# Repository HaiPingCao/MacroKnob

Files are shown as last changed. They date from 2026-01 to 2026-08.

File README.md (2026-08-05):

# ControlDeck

ControlDeck is a simple, multi-purpose, programmable volume knob built with an Arduino Pro Micro.  
It is designed as a compact hardware control interface for volume adjustment, mode switching, and custom hotkeys.

! Please ignore the grammar error, my English is bad 😭
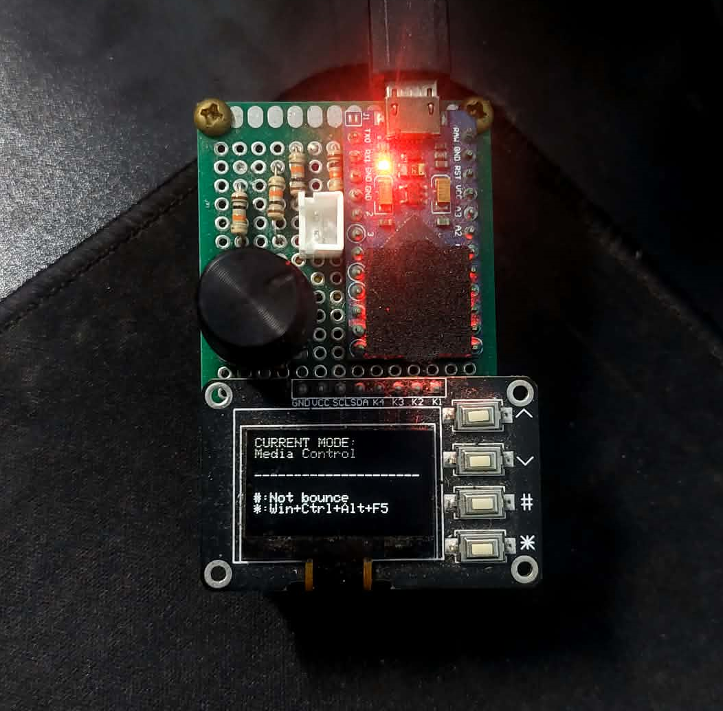
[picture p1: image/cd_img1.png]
This is my build


## Hardware

The project uses the following components:

- Arduino Pro Micro
- Rotary encoder with integrated push button
- 4 momentary push buttons
- SSD1306 OLED display (128×64)

### Circuit Setup and Wiring

| Component | Pin | Description |
| --- | --- | --- |
| Encoder CLK | 5 | Clock signal for rotation detection |
| Encoder DT  | 4 | Data signal for rotation direction detection |
| Encoder SW  | 6 | Encoder push button |
| UP Button | 10  | Switch to previous mode |
| DOWN Button | 16  | Switch to next mode |
| # Button | 14  | Special function button |
| \* Button | 15  | Triggers Win + Ctrl + Alt + F5 hotkey |

## Software

### Required Libraries

When using the Arduino IDE, install the following libraries via the Arduino Library Manager:

- **HID-Project** by NicoHood
- **Adafruit GFX Library** by Adafruit
- **Adafruit SSD1306** by Adafruit

### Driver Development

A new custom driver written in Rust is currently in early development to support more advanced features.  
See the `mk-driver` directory for details.

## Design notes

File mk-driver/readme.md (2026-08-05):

# MK Driver (a.k.a macro knob driver)

## ⚠ I postponed the development of this driver due to a lack of time, and I am already satisfied with the current build.

A volume monitor that sends real-time audio volume data to Arduino via serial port.

## Features

- Monitors system volume in real-time
- Sends volume data to Arduino via serial connection
- Auto-detects Arduino port

## Requirements

- Rust (latest stable version)
- Arduino connected via USB and open serial port

## Usage

1. Connect your Arduino via USB
2. Upload the Arduino sketch to your board
3. Run the program:

```bash
cargo run
```

The program will:

- Auto-detect the Arduino port
- Connect at 9600 baud rate
- Send volume updates when changes are detected

## Data Format

The program sends 2 bytes per update:

- Byte 1: Volume level (0-100)
- Byte 2: Mute status (0 = unmuted, 1 = muted)

## Supported Platforms

- Windows
- Linux

## Troubleshooting

**Arduino not found**

- Ensure Arduino is connected via USB
- Check if Arduino drivers are installed

**Timeout errors**

- Volume changes are only sent when detected to prevent serial overload
- Check Arduino serial buffer if issues persist
- Only one program can access the serial port at a time
- Try close Arduino IDE Serial Monitor or any other program using the serial port

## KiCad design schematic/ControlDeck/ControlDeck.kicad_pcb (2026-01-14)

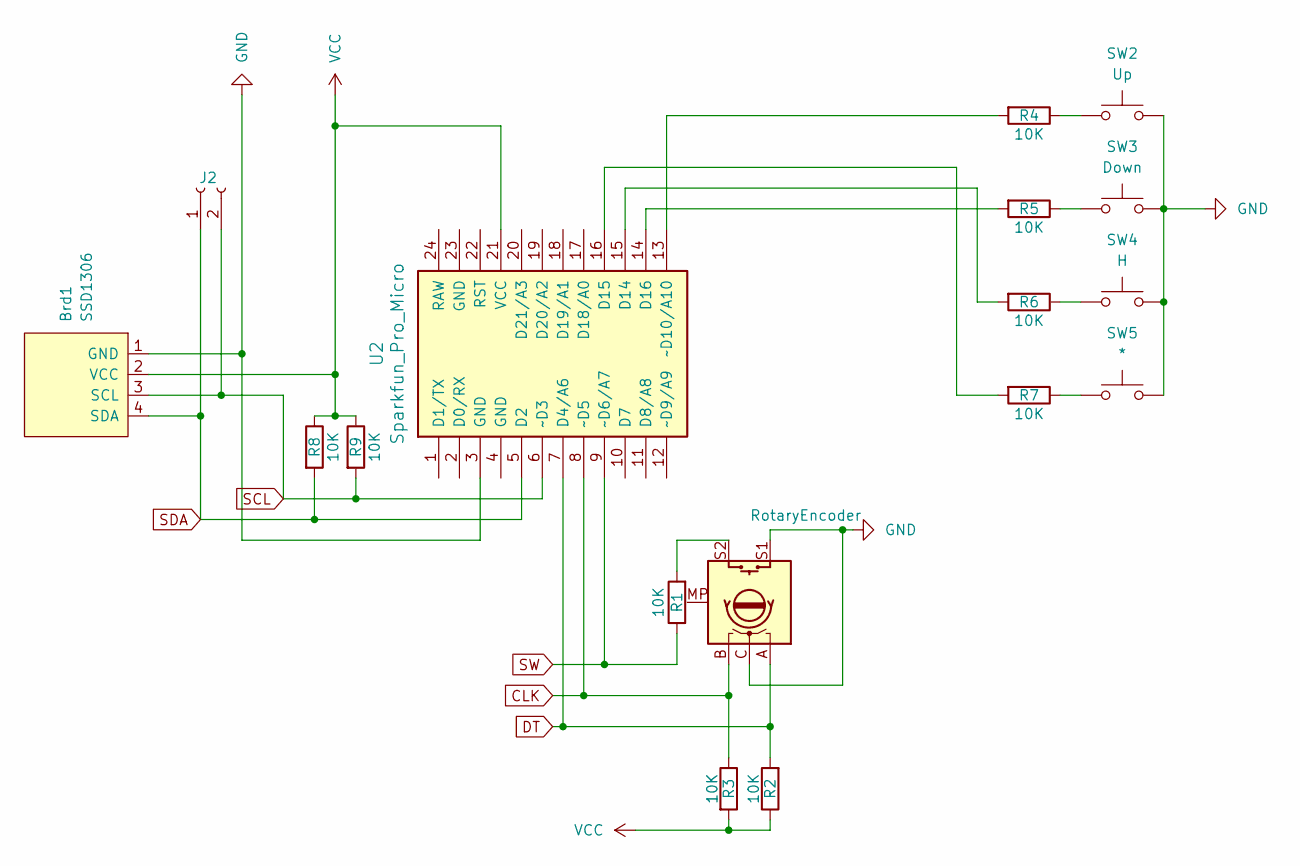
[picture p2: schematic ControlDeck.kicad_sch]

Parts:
Brd1: SSD1306; 128x64OLED
J2: Conn_01x02_Socket; JST_PH_B2B-PH-K_1x02_P2.00mm_Vertical
R1, R2, R3, R4, R5, R6, R7, R8, R9: 10K; R_Axial_DIN0204_L3.6mm_D1.6mm_P5.08mm_Horizontal
SW1: RotaryEncoder; RotaryEncoder_Alps_EC11E-Switch_Vertical_H20mm
SW2: Up; SW_SPST_CK_RS282G05A3
SW3: Down; SW_SPST_CK_RS282G05A3
SW4: H; SW_SPST_CK_RS282G05A3
SW5: *; SW_SPST_CK_RS282G05A3
U2: Sparkfun_Pro_Micro

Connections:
CLK: R3.1, SW1.B, U2.8 (~D5)
DT: R2.2, SW1.A, U2.7 (D4/A6)
GND: Brd1.1 (GND), SW1.C, SW1.S1, SW2.2, SW3.2, SW4.2, SW5.2, U2.3 (GND), U2.23 (GND)
unnamed: R1.2, SW1.S2
unnamed: R4.1, SW2.1
unnamed: R5.1, SW3.1
unnamed: R6.1, SW4.1
unnamed: R7.1, SW5.1
unnamed: R6.2, U2.15 (D14)
unnamed: R7.2, U2.16 (D15)
unnamed: R5.2, U2.14 (D16)
unnamed: R4.2, U2.13 (~D10/A10)
SCL: Brd1.3 (SCL), J2.2, R9.2, U2.6 (~D3)
SDA: Brd1.4 (SDA), J2.1, R8.2, U2.5 (D2)
SW: R1.1, U2.9 (~D6/A7)
VCC: Brd1.2 (VCC), R2.1, R3.2, R8.1, R9.1, U2.21 (VCC)

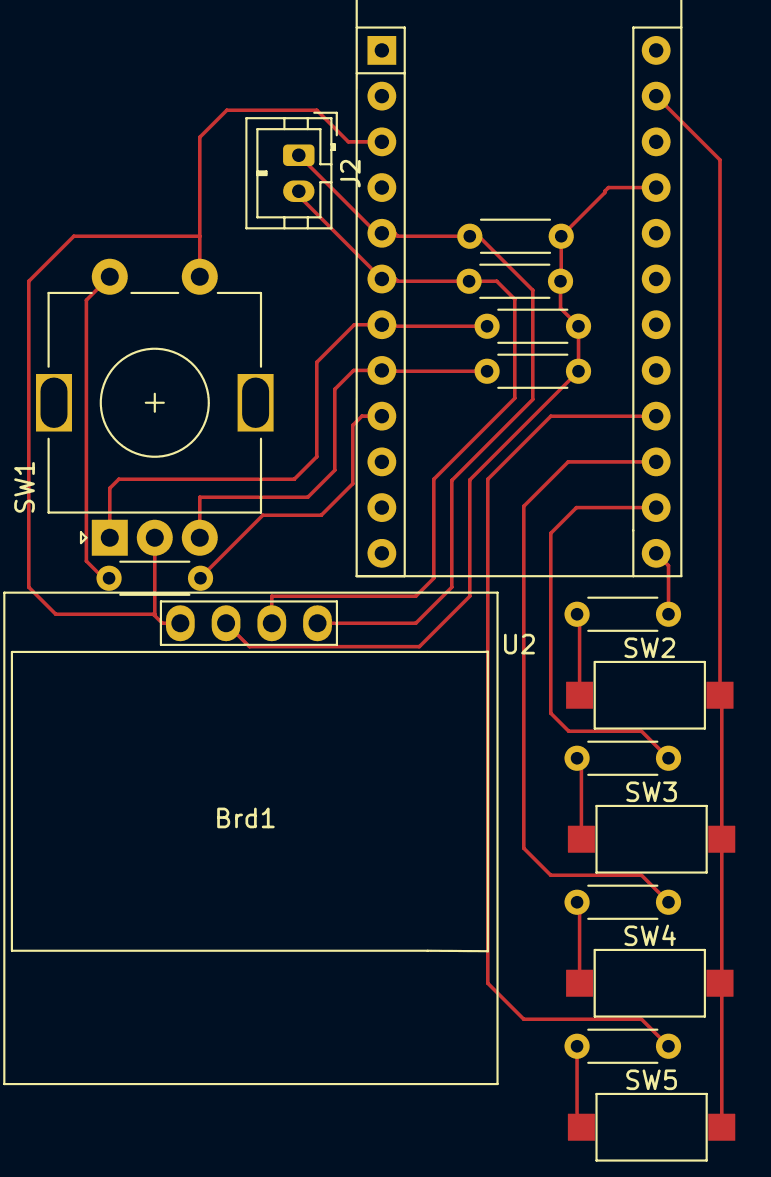
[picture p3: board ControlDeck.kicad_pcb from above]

Board: 2 copper layers, 17 parts (0 on the bottom side), 16 nets.

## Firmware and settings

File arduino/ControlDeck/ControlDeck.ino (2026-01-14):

#include <HID-Project.h>
#include <Adafruit_GFX.h>
#include <Adafruit_SSD1306.h>
#include "keyCombination.h"

// Encoder rotary pins
#define CLK 5
#define DT 4
#define SW 6
// Control button pins
#define BTN_UP 10
#define BTN_DOWN 16
#define BTN_NUMBER_SIGN 14
#define BTN_ASTERISK 15
// OLED setup
#define SCREEN_WIDTH 128
#define SCREEN_HEIGHT 64
#define OLED_ADDR 0x3C

// Global variables
int currentMode = 1;              // Current operating mode (1-4)
const int maxMode = 4;            // Total number of modes
unsigned long lastButtonPress = 0; // For debouncing

// Init display
Adafruit_SSD1306 display(SCREEN_WIDTH, SCREEN_HEIGHT, &Wire, -1);

// Function prototypes
void updateDisplay();
String modeToString(int mode);
void rotateERLeft();
void rotateERRight();
void pressERButton();
void switchDesktopRight();
void switchDesktopLeft();
void createNewDesktop();
void goToDesktop();

void setup() {
  // Initialize inputs
  pinMode(CLK, INPUT);
  pinMode(DT, INPUT);
  pinMode(SW, INPUT_PULLUP);
  pinMode(BTN_UP, INPUT_PULLUP);
  pinMode(BTN_DOWN, INPUT_PULLUP);
  pinMode(BTN_NUMBER_SIGN, INPUT_PULLUP);
  pinMode(BTN_ASTERISK, INPUT_PULLUP);

  // Initialize OLED
  if (!display.begin(SSD1306_SWITCHCAPVCC, OLED_ADDR)) {
    for (;;); // Halt if display fails
  }
  
  display.clearDisplay();
  display.setTextSize(1);
  display.setTextColor(SSD1306_WHITE);
  updateDisplay();

  // Initialize HID
  Consumer.begin();
  Keyboard.begin();
  BootMouse.begin();
  BootKeyboard.begin();
}

void loop() {
  // Debounce timing
  const unsigned long debounceTime = 500;
  unsigned long currentTime = millis();
  
  // Handle encoder rotation
  static int lastStateCLK = digitalRead(CLK);
  int currentStateCLK = digitalRead(CLK);

  // Check if encoder rotated
  if (currentStateCLK != lastStateCLK) {
    if (digitalRead(DT) != currentStateCLK) {
      rotateERLeft();  // Counter-clockwise
    } else {
      rotateERRight(); // Clockwise
    }
  }
  lastStateCLK = currentStateCLK;

  // Handle encoder button press
  if (digitalRead(SW) == LOW && (currentTime - lastButtonPress > debounceTime)) {
    pressERButton();
    lastButtonPress = currentTime;
  }

  // Handle UP button - previous mode
  if (!digitalRead(BTN_UP) && (currentTime - lastButtonPress > debounceTime)) {
    currentMode = (currentMode == 1) ? maxMode : currentMode - 1;
    updateDisplay();
    lastButtonPress = currentTime;
  }

  // Handle DOWN button - next mode
  if (!digitalRead(BTN_DOWN) && (currentTime - lastButtonPress > debounceTime)) {
    currentMode = (currentMode % maxMode) + 1;
    updateDisplay();
    lastButtonPress = currentTime;
  }

  // Handle * button - special hotkey
  if (digitalRead(BTN_ASTERISK) == LOW && (currentTime - lastButtonPress > debounceTime)) {
    winCtrlAltF5();
    lastButtonPress = currentTime;
  }
  
  delay(1);
}

void updateDisplay() {
  display.clearDisplay();
  display.setCursor(0, 0);

  // Show current mode
  display.println("CURRENT MODE:");
  display.println(modeToString(currentMode));
  display.println("\n---------------------\n");
  display.println("#:Not bounce");
  display.println("*:Win+Ctrl+Alt+F5");
  display.display();
}

String modeToString(int mode) {
  switch (mode) {
    case 1: return "Volume Control";
    case 2: return "Media Control";
    case 3: return "Mouse Scroll";
    case 4: return "Desktop Mgmt";
    default: return "Unknown";
  }
}

void rotateERRight() {
  switch (currentMode) {
    case 1:
      Consumer.write(MEDIA_VOLUME_UP);
      break;
    case 2:
      Consumer.write(MEDIA_NEXT);
      break;
    case 3:
      BootMouse.move(0, 0, -1); // Scroll down
      break;
    case 4:
      switchDesktopRight();
      break;
  }
}

void rotateERLeft() {
  switch (currentMode) {
    case 1:
      Consumer.write(MEDIA_VOLUME_DOWN);
      break;
    case 2:
      Consumer.write(MEDIA_PREVIOUS);
      break;
    case 3:
      BootMouse.move(0, 0, 1); // Scroll up
      break;
    case 4:
      switchDesktopLeft();
      break;
  }
}

void pressERButton() {
  switch (currentMode) {
    case 1:
      Consumer.write(MEDIA_VOLUME_MUTE);
      break;
    case 2:
      Consumer.write(MEDIA_PLAY_PAUSE);
      break;
    case 3:
      goToDesktop();
      break;
    case 4:
      createNewDesktop();
      break;
  }
}

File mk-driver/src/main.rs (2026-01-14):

// use std::io::Write;
use std::thread;
use std::time::Duration;

use serialport::SerialPort;

mod arduino;
mod utils;

#[cfg(target_os = "linux")]
mod linux;

#[cfg(target_os = "windows")]
mod windows;

fn main() {
    let arduino_port = match arduino::find() {
        Some(port) => port,
        None => {
            eprintln!("Arduino not found!");
            return;
        }
    };

    let mut port = serialport::new(&arduino_port, 9600)
        .timeout(Duration::from_millis(3000))
        .open()
        .expect("Failed to open port");

    port.write_data_terminal_ready(false).ok();

    println!("Connected to Arduino on {}", arduino_port);

    thread::sleep(Duration::from_millis(500));

    run(port);
}

#[cfg(target_os = "windows")]
fn run(mut port: Box<dyn SerialPort>) {
    let mut last_volume = 255;
    let mut last_muted = false;

    loop {
        match windows::get_volume() {
            Ok((current_volume, is_muted)) => {
                if current_volume != last_volume || is_muted != last_muted {
                    let data = [current_volume, if is_muted { 1 } else { 0 }];

                    match port.write_all(&data) {
                        Ok(_) => {
                            port.flush().ok();
                            println!(
                                "{}",
                                if is_muted {
                                    format!("Muted (Volume: {}%)", current_volume)
                                } else {
                                    format!("Volume: {}%", current_volume)
                                }
                            );
                            last_volume = current_volume;
                            last_muted = is_muted;
                        }
                        Err(e) => {
                            eprintln!("Failed to send: {}", e);
                            thread::sleep(Duration::from_millis(500));
                        }
                    }
                }
            }
            Err(e) => eprintln!("Failed to get volume: {}", e),
        }

        thread::sleep(Duration::from_millis(100));
    }
}

#[cfg(target_os = "linux")]
fn run(mut port: Box<dyn SerialPort>) {
    let mut last_volume = 255;
    let mut last_muted = false;

    loop {
        match linux::get_volume() {
            Ok((current_volume, is_muted)) => {
                if current_volume != last_volume || is_muted != last_muted {
                    let data = [current_volume, if is_muted { 1 } else { 0 }];

                    match port.write_all(&data) {
                        Ok(_) => {
                            port.flush().ok();
                            println!(
                                "{}",
                                if is_muted {
                                    format!("Muted (Volume: {}%)", current_volume)
                                } else {
                                    format!("Volume: {}%", current_volume)
                                }
                            );
                            last_volume = current_volume;
                            last_muted = is_muted;
                        }
                        Err(e) => {
                            eprintln!("Failed to send: {}", e);
                            thread::sleep(Duration::from_millis(500));
                        }
                    }
                }
            }
            Err(e) => eprintln!("Failed to get volume: {}", e),
        }

        thread::sleep(Duration::from_millis(100));
    }
}

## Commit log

2025-06-23 update schematic & pcb
    [MacroKnob.kicad_pcb, MacroKnob.kicad_sch]
2025-06-23 Update Schematic
    [MacroKnob.kicad_sch]
2025-06-23 Add Script for arduino
    [MacroKnob.kicad_pcb, MacroKnob.kicad_sch]
2025-10-03 modified: MacroKnob/MacroKnob.kicad_pro modified: README.md
2026-01-14 modified: .gitignore new file: mk-driver/Cargo.toml new file: mk-driver/readme.md new file: mk-driver/src/arduino.rs new file: mk-driver/src/linux/mod.rs new file: mk-driver/src/linux/volume_action_l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
2026-01-14 update readme for mk-driver
2026-08-05 modified: README.md new file: image/cd_img1.png modified: mk-driver/readme.md
